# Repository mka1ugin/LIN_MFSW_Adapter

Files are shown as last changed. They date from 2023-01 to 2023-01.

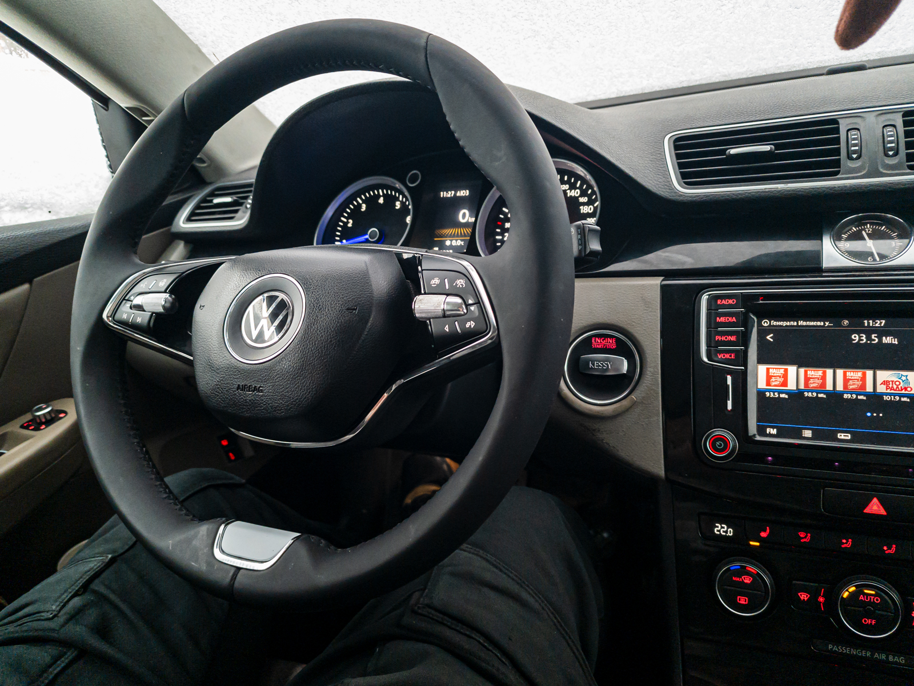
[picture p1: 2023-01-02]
skoda_mqb_steering_on_pq46.jpg

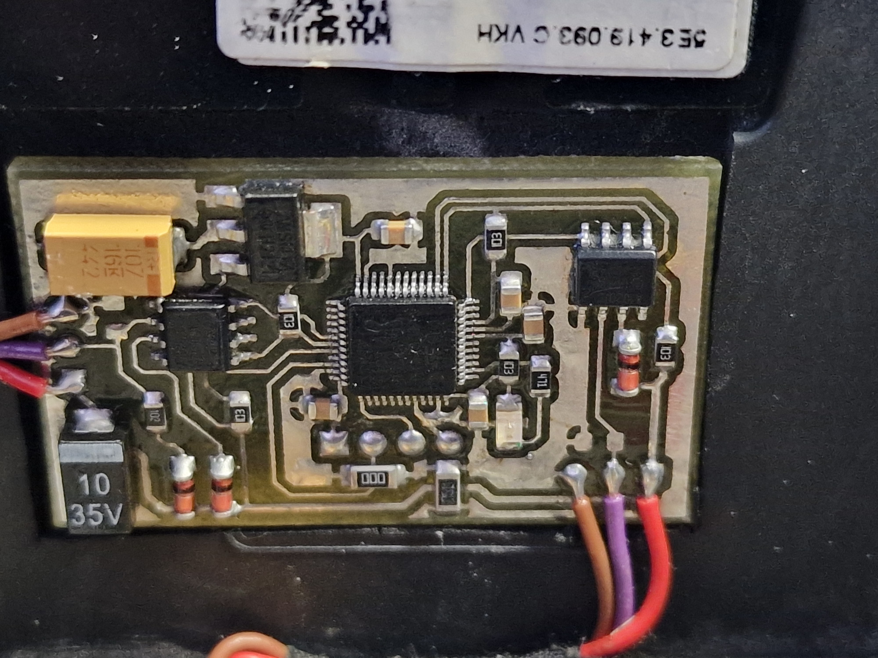
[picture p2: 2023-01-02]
HW/device.jpg

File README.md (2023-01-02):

# LIN_MFSW_Adapter

Проект адаптера для установки новых MQB мультирулей на автомобили платформы PQ.

Аппаратно адаптер выполнен на микроконтроллере STM32F103C8T6, схема и печатная плата разработаны в среде KiCad. Печатная плата односторонняя, габаритные размеры 43 x 26 мм.
В микроконтроллере задействованы 2 UART-порта, сконфигурированные в режиме LIN. UART1 работает в режиме Master и отправляет запросы на блок кнопок, UART2 в режиме Slave
обрабатывает запросы от подрулевого блока.
Прошивка написана в среде Keil 5 с использованием STM32Cube MX. Все действия выполняются в callback-функциях по окончании приёма/передачи по UART. 

Устройство испытано на VW Passat B6 с подрулевым блоком 5K0953569T (SW 0180) и мультирулём 5E3419093CVKH. Его кнопки максимально имитируют работу кнопок старого 12-кнопочного
руля. Кнопки вызова ассистентов, управления обогревом руля и включения круиза пока не задействованы.
Сам адаптер установлен прямо в мультируль, под него вырезано место (на версиях мультируля с датчиками KLR здесь установлен контроллер KLR).
skoda_mqb_steering_on_pq46
device

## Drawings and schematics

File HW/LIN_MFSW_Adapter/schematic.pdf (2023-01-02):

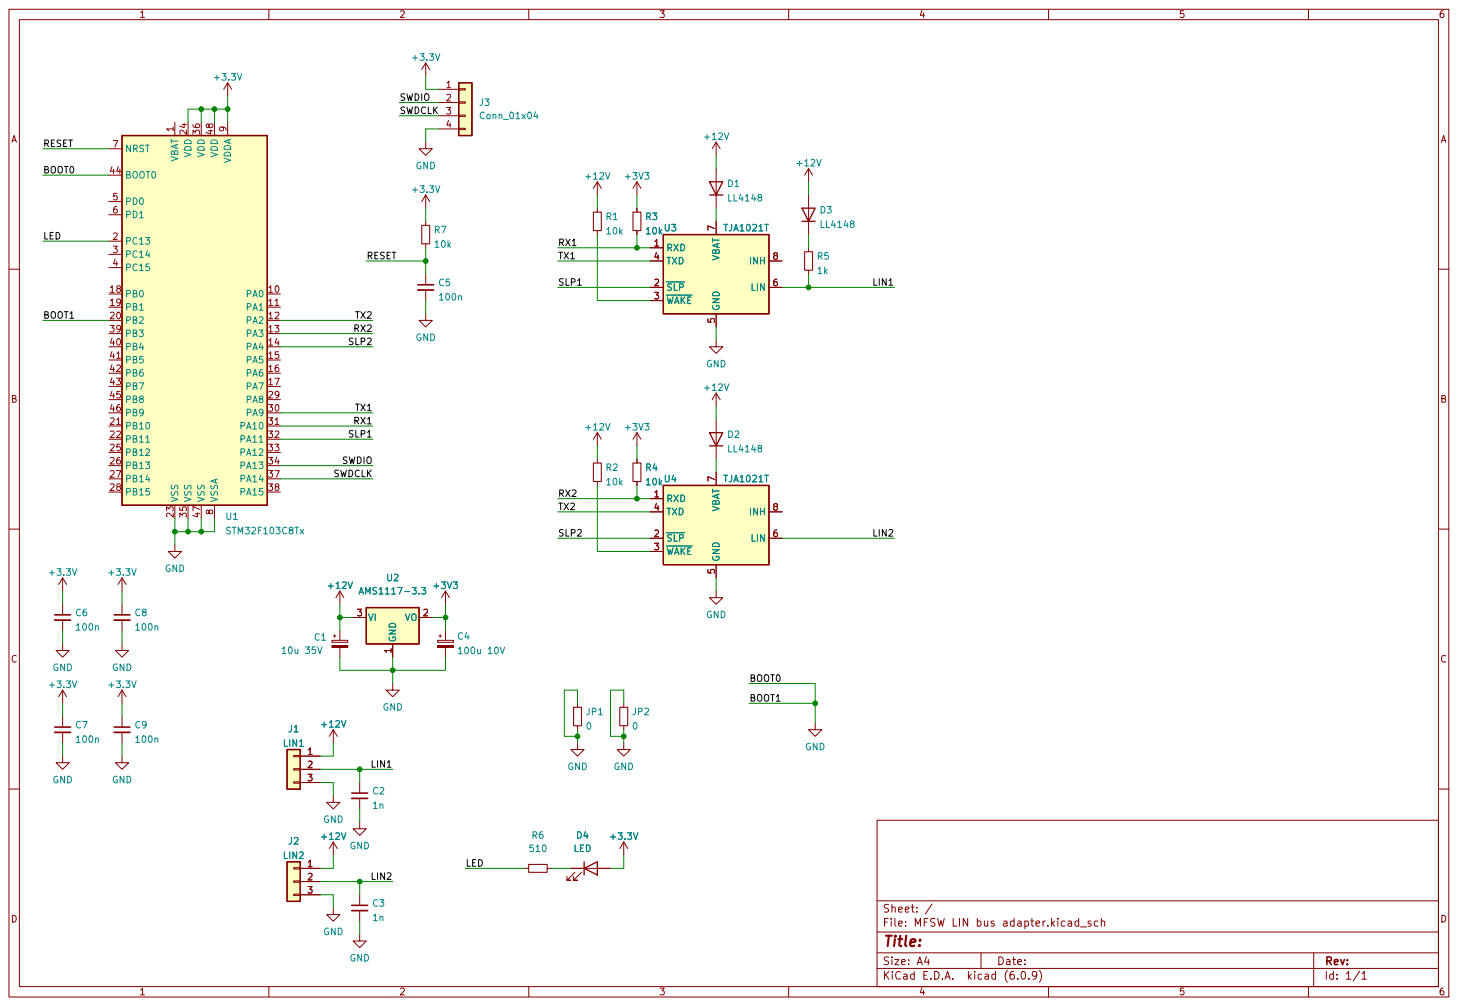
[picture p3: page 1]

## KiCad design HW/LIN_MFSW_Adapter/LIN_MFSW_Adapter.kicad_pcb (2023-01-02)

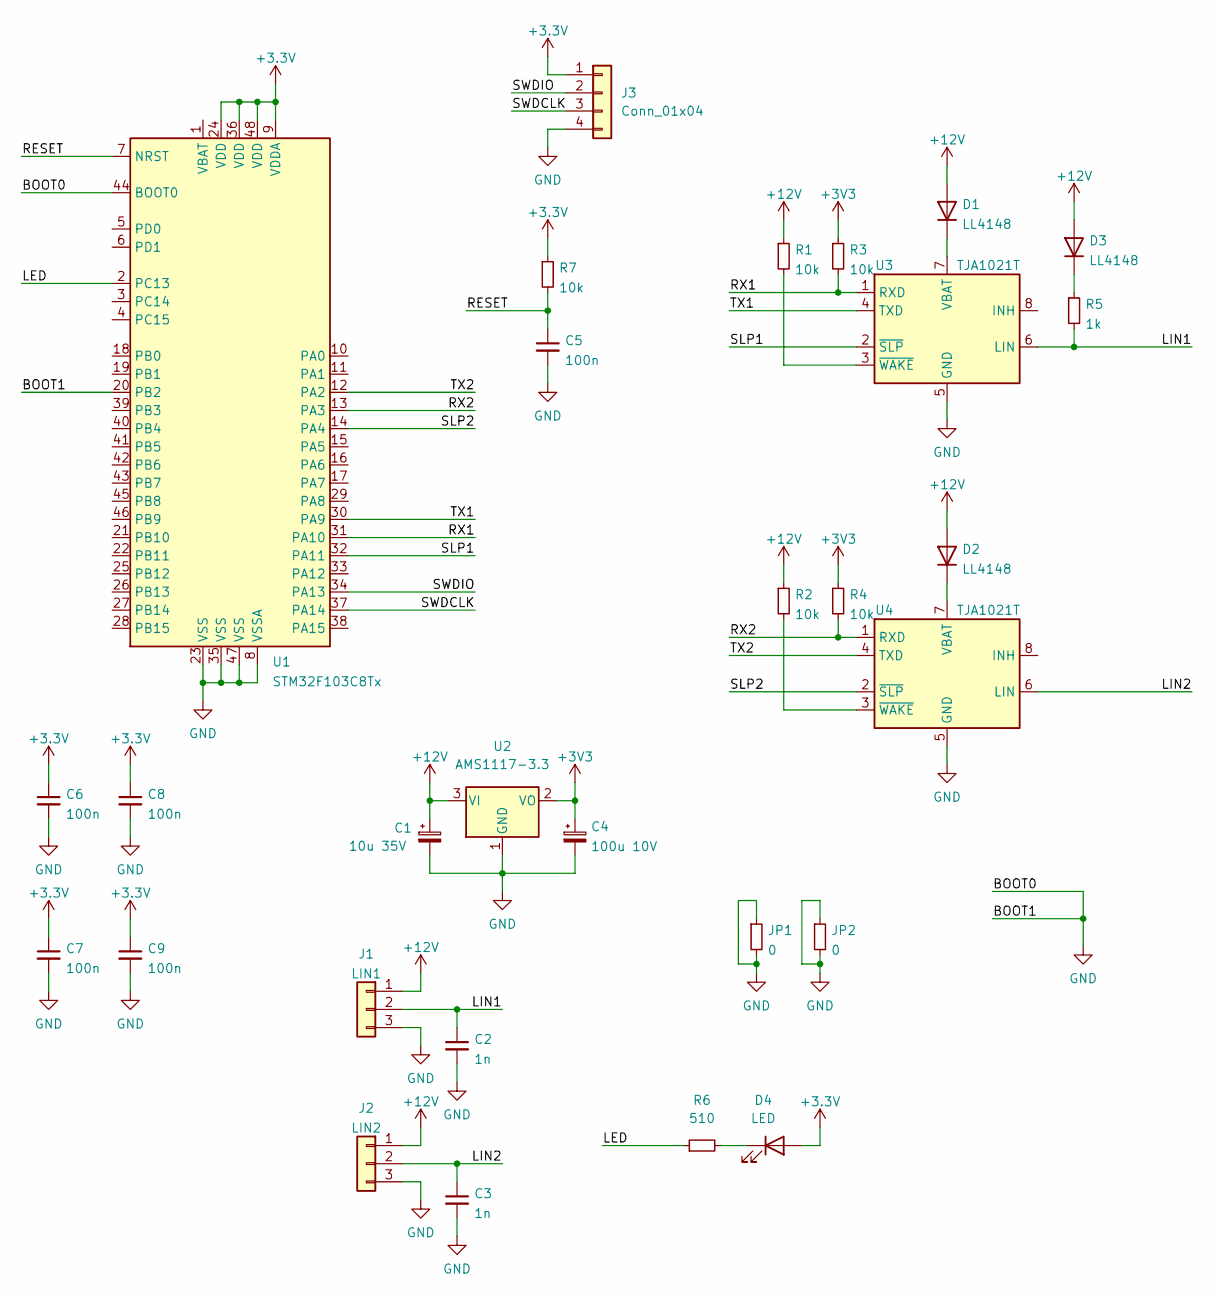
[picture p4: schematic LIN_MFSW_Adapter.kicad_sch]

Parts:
C1: 10u 35V; CP_EIA-7343-31_Kemet-D_Pad2.25x2.55mm_HandSolder
C2, C3: 1n; C_0805_2012Metric_Pad1.18x1.45mm_HandSolder
C4: 100u 10V; CP_EIA-7343-31_Kemet-D_Pad2.25x2.55mm_HandSolder
C5, C6, C7, C8, C9: 100n; C_0805_2012Metric_Pad1.18x1.45mm_HandSolder
D1, D2, D3: LL4148; D_MiniMELF
D4: LED; LED_1206_3216Metric_Pad1.42x1.75mm_HandSolder
J1: LIN1; PinHeader_1x03_P2.54mm_Vertical
J2: LIN2; PinHeader_1x03_P2.54mm_Vertical
J3: Conn_01x04; JTAG_SMD_CONNECTOR
JP1, JP2: 0; R_1206_3216Metric_Pad1.30x1.75mm_HandSolder
R1, R2, R3, R4, R7: 10k; R_0805_2012Metric_Pad1.20x1.40mm_HandSolder
R5: 1k; R_0805_2012Metric_Pad1.20x1.40mm_HandSolder
R6: 510; R_0805_2012Metric_Pad1.20x1.40mm_HandSolder
U1: STM32F103C8Tx; LQFP-48_7x7mm_P0.5mm
U2: AMS1117-3.3; SOT-223-3_TabPin2
U3, U4: TJA1021T; SOIC-8_3.9x4.9mm_P1.27mm

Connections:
+12V: C1.1, D1.2 (A), D2.2 (A), D3.2 (A), J1.1, J2.1, R1.1, R2.1, U2.3 (VI)
/LED: R6.1, U1.2 (PC13)
/LIN1: C2.1, J1.2, R5.2, U3.6 (LIN)
/LIN2: C3.1, J2.2, U4.6 (LIN)
/RESET: C5.1, R7.2, U1.7 (NRST)
/RX1: R3.2, U1.31 (PA10), U3.1 (RXD)
/RX2: R4.2, U1.13 (PA3), U4.1 (RXD)
/SLP1: U1.32 (PA11), U3.2 (~SLP)
/SLP2: U1.14 (PA4), U4.2 (~SLP)
/SWDCLK: J3.3, U1.37 (PA14)
/SWDIO: J3.2, U1.34 (PA13)
/TX1: U1.30 (PA9), U3.4 (TXD)
/TX2: U1.12 (PA2), U4.4 (TXD)
GND: C1.2, C2.2, C3.2, C4.2, C5.2, C6.2, C7.2, C8.2, C9.2, J1.3, J2.3, J3.4, JP1.1, JP1.2, JP2.1, JP2.2, U1.8 (VSSA), U1.20 (PB2), U1.23 (VSS), U1.35 (VSS), U1.44 (BOOT0), U1.47 (VSS), U2.1 (GND), U3.5 (GND), U4.5 (GND)
unnamed: D1.1 (K), U3.7 (VBAT)
unnamed: D2.1 (K), U4.7 (VBAT)
unnamed: D3.1 (K), R5.1
unnamed: D4.1 (K), R6.2
unnamed: R1.2, U3.3 (~WAKE)
unnamed: R2.2, U4.3 (~WAKE)

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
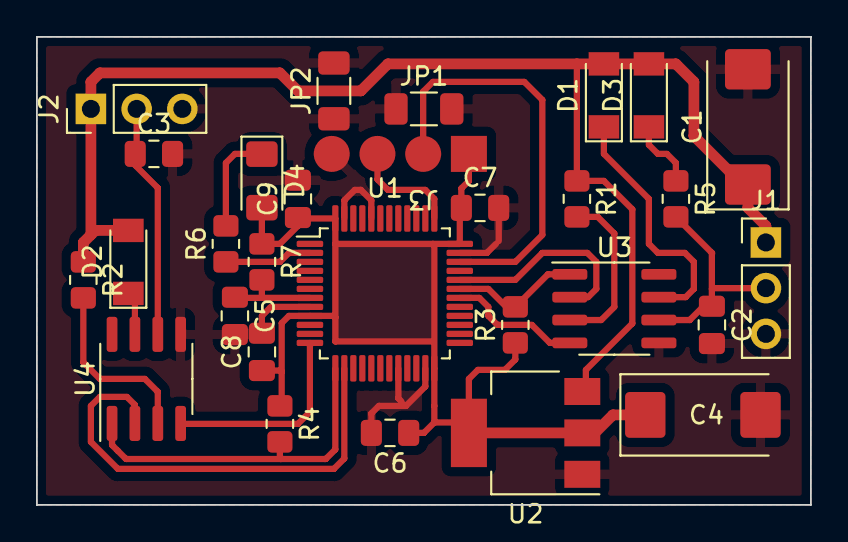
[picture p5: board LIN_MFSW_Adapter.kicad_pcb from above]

Board: 2 copper layers, 43.0 x 26.0 mm, 29 parts (0 on the bottom side), 21 nets.

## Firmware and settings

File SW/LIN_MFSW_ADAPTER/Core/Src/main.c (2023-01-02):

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
/* Includes ------------------------------------------------------------------*/
#include "main.h"

IWDG_HandleTypeDef hiwdg;

UART_HandleTypeDef huart1;
UART_HandleTypeDef huart2;

/* USER CODE BEGIN PV */

uint8_t buttonData[BUTTONS_LEN];
uint8_t statusData[STATUS_LEN];
uint8_t tempData[TEMP_LEN];
uint8_t buttonBuf[BUTTONS_LEN];
uint8_t statusBuf[STATUS_LEN];
uint8_t tempBuf[TEMP_LEN];
uint8_t diagRqBuf[DIAG_RQ_LEN];
HAL_StatusTypeDef sendResult;
HAL_StatusTypeDef readResult;

/* USER CODE END PV */

void SystemClock_Config(void);
static void MX_GPIO_Init(void);
static void MX_USART1_UART_Init(void);
static void MX_USART2_UART_Init(void);
static void MX_IWDG_Init(void);
/* USER CODE BEGIN 0 */
LIN_State slaveState = LIN_RECEIVING_BREAK;
/* USER CODE END 0 */

/**
  * @brief  The application entry point.
  * @retval int
  */
int main(void)

{
  /* MCU Configuration--------------------------------------------------------*/

  /* Reset of all peripherals, Initializes the Flash interface and the Systick. */
  HAL_Init();

  /* Configure the system clock */
  SystemClock_Config();

  /* Initialize all configured peripherals */
  MX_GPIO_Init();
  MX_USART1_UART_Init();
  MX_USART2_UART_Init();
  MX_IWDG_Init();
  /* USER CODE BEGIN 2 */
	
	HAL_GPIO_WritePin(GPIOA, GPIO_PIN_4, GPIO_PIN_SET);
	HAL_GPIO_WritePin(GPIOA, GPIO_PIN_11, GPIO_PIN_SET);
	
	__HAL_UART_ENABLE_IT(&huart2, UART_IT_LBD);
	__HAL_UART_ENABLE_IT(&huart2, UART_IT_RXNE);
	__HAL_UART_DISABLE_IT(&huart1, UART_IT_LBD);
	
  /* USER CODE END 2 */

  /* Infinite loop */
  /* USER CODE BEGIN WHILE */
	
	
  while (1)
  {		
    /* USER CODE END WHILE */

    /* USER CODE BEGIN 3 */
  }
  /* USER CODE END 3 */
}

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
/* USER CODE BEGIN 4 */
HAL_StatusTypeDef linSend(UART_HandleTypeDef *huart, uint8_t id, uint8_t data[], uint8_t len)
{
	uint8_t linSync = LIN_SYNC_BYTE;
	uint8_t buf[len + 2];
	buf[0] = linSync;
	buf[1] = id;
	for (int i = 0; i < len + 2; i++)
	{
		buf[i + 2] = data[i];
	}
	HAL_LIN_SendBreak(huart);
	HAL_StatusTypeDef result = HAL_UART_Transmit_IT(huart, buf, len + 2);
	return result;
}

HAL_StatusTypeDef linRead(UART_HandleTypeDef *huart, uint8_t id, uint8_t data[], uint8_t len)
{
	uint8_t linSync = LIN_SYNC_BYTE;
	uint8_t txbuf[2];
	txbuf[0] = linSync;
	txbuf[1] = id;
	HAL_LIN_SendBreak(huart);
	sendResult = HAL_UART_Transmit_IT(huart, txbuf, 2);
	if (sendResult != HAL_OK) {
		return sendResult;
	}
	readResult = HAL_UART_Receive_IT(huart, data, len);
	return readResult;
}

HAL_StatusTypeDef linRequest(UART_HandleTypeDef *huart, uint8_t id)
{
	uint8_t linSync = LIN_SYNC_BYTE;
	uint8_t txbuf[2];
	txbuf[0] = linSync;
	txbuf[1] = id;
	HAL_LIN_SendBreak(huart);
	sendResult = HAL_UART_Transmit_IT(huart, txbuf, 2);
	return sendResult;
}
uint8_t LIN_CalcCheckSum(uint8_t *id, uint8_t *data, uint8_t len)
{
  uint16_t sum = 0;
	sum += *id;
  
  for (uint8_t i = 0; i < len; i++)
  {
    sum += data[i];
  }
  
  while(sum > 0xFF)
  {
    sum -= 0xFF;
  }
  
  sum = 0xFF - sum;
  
  return (uint8_t)sum;
}

void blink(void)
{
	HAL_GPIO_TogglePin(Led_GPIO_Port, Led_Pin);
}
/* USER CODE END 4 */
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


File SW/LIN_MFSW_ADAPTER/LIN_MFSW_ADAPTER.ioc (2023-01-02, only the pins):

Mcu.UserName=STM32F103C8Tx
PA10.Signal=USART1_RX
PA11.GPIO_Label=SLP1
PA11.Signal=GPIO_Output
PA13.Signal=SYS_JTMS-SWDIO
PA14.Signal=SYS_JTCK-SWCLK
PA2.Signal=USART2_TX
PA3.Signal=USART2_RX
PA4.GPIO_Label=SLP2
PA4.Signal=GPIO_Output
PA9.Signal=USART1_TX
PB3.Signal=SYS_JTDO-TRACESWO
PC13-TAMPER-RTC.GPIO_Label=Led
PC13-TAMPER-RTC.Signal=GPIO_Output
PD0-OSC_IN.Signal=RCC_OSC_IN
PD1-OSC_OUT.Signal=RCC_OSC_OUT

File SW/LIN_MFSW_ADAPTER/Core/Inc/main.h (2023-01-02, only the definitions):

#define BUTTONS_ID	0x8E
#define STATUS_ID		0x0D
#define DIAG_ID			0x3C
#define DIAG_RS_ID	0x7D
#define TEMP_ID			0xBA
#define BUTTONS_LEN	9
#define STATUS_LEN	5
#define TEMP_LEN		3
#define DIAG_RQ_LEN	9
#define LIN_SYNC_BYTE	0x55
#define TIMEOUT 5
#define HEADER_LEN 3
#define Led_Pin GPIO_PIN_13
#define Led_GPIO_Port GPIOC
#define SLP2_Pin GPIO_PIN_4
#define SLP2_GPIO_Port GPIOA
#define SLP1_Pin GPIO_PIN_11
#define SLP1_GPIO_Port GPIOA

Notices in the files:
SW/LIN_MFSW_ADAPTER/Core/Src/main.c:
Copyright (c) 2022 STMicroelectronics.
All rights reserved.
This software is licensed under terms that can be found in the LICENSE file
